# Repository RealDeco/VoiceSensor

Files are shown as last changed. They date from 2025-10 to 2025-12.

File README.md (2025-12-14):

<p align="center">
  
  
  
</p>

# 🎙️ VoiceSensor • VoiceEar • VoiceScreen

## Overview

For years, I’ve been advocating for **speakerless voice assistants** — mainly because 99% of us already have a media player in our homes, right?

This project contains three companion devices designed to work with Home Assistant and ESPHome: **VoiceSensor**, **VoiceEar**, and **VoiceScreen**.

---

## 🟦 VoiceSensor

The original prototype of this project (and the name of this repo).

It was a single device containing:

* a microphone
* a presence sensor
* a light sensor

The idea: these sensors naturally belong together and are usually mounted in the same place — high on a wall or ceiling.

---

## 🟩 VoiceEar ( the $4 VA :)

A simpler version of VoiceSensor.
It contains **only a microphone**, acting purely as an “ear” for your voice assistant.

Audio responses can be sent to **any Home Assistant media player**, so the device itself does not need a speaker.

---

## 📡 Event Outputs

All devices — VoiceSensor, VoiceEar, Respeaker Lite, and the entire Xiaozhi-ESPHome lineup — send the following events:

* **Audio Path**
  Used to route the assistant’s audio output to any chosen media player via automation.

* **Request Text**
  The recognized speech (what the user asked).
  Can be forwarded to VoiceScreen or a dashboard.

* **Response Text**
  The assistant’s reply in text form.
  Also sendable to VoiceScreen or dashboards.

* **Phase ID**
  The current pipeline step.
  Useful for showing different visuals on VoiceScreen depending on the assistant’s state.

---

## 🖥️ VoiceScreen

VoiceScreen is an ESP32-S3 display that acts as a **visual companion** to VoiceSensor, VoiceEar, and all devices from the Xiaozhi-ESPHome repository.

It waits for incoming events and updates the display accordingly.
Touching the screen sends button events back to the selected voice assistant device (e.g., Start / Stop listening).

---

<p align="center">

## 🟦 VoiceSensor DIY images
  
  
  
</p>

<p align="center">
  
  
</p>

## 🟩 VoiceEar DIY images

<p align="center">
  
  
  
  

Schematics

  
  
</p>

---

## 📄 Files

### **`VoiceSensor.yaml` (ESP32-S3 Zero + inmp441 mic + ld2410c presence sensor + bm1750 light sensor)**

* Works **only** with **ESP32-S3 Zero** (not SuperMini).
* Zero includes **2MB PSRAM**, required for on-device MicroWakeWord.
* Supports **up to 2 wake words**, processed locally.
* For outputting responses to an external media player, look in automations

---

### **`VoiceEar.yaml` (ESP32-S3 Zero + inmp441 mic, no sensors)**

* Just the "Ear" (no sensors) version of "VoiceSensor"

---

### **`respeaker-satellite-base.yaml` custom version of the  official Respeaker-Lite-ESPHome-integration**

* Use the original placement of the file (esphome/common/)

---

### **`VoiceScreen.yaml` (Guition 4" 4848S040 with no mic.)**

* Simple yaml that reads the phase id's from HA and display images accordingly
* Can also control the "virtual touch" of the voicesensor by touching the display.

---

## 🛠️ Parts List

### **VoiceSensor Setup (Full Device)**

* **ESP32-S3 Zero**
* **INMP441 microphone**
* **LD2410C presence sensor**
* **BH1750 ambient light sensor**
* **16mm push button** (GPIO 10)

### **Ear-Only Setup (No Sensors)**

* **ESP32-S3 Zero**
* **INMP441 microphone**

---

## 📦 Assembly Notes (VoiceSensor)

* Designed to fit inside a custom enclosure with accessible test pins.
* **Minimal soldering required**, unless:

  * You need custom power splitters.
  * Pin headers arrive loose or unsoldered.

---

## ✨ Features (Voicesensor)

* 🗣️ **Local Voice Assistant**
  On-device processing with LED phase feedback.

* 👤 **Presence Detection**
  LD2410C millimeter-wave radar sensor.

* 💡 **Light Level Monitoring**
  BH1750 digital luminance sensor.

* 🔘 **Push Button Input**
  For triggering actions manually.

* 🔧 **Maker-Friendly**
  Fully testable on a breadboard before final assembly.

---

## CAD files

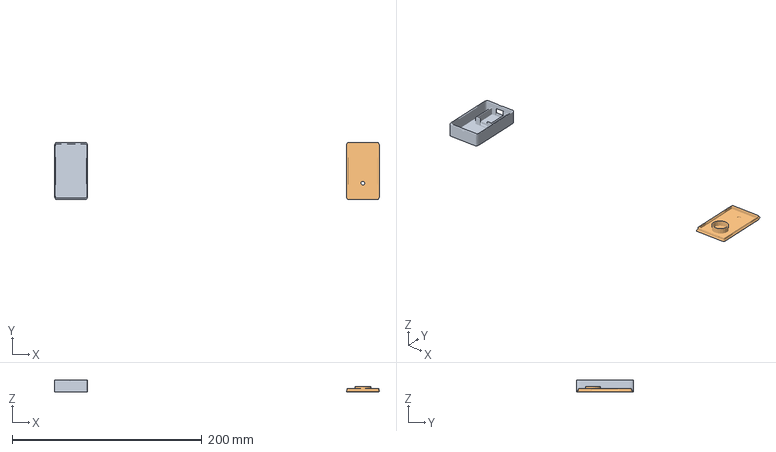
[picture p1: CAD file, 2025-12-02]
3D_files/VoiceEar.3mf
342.2 x 60.0 x 13.0 mm
ear_bottom
ear_top

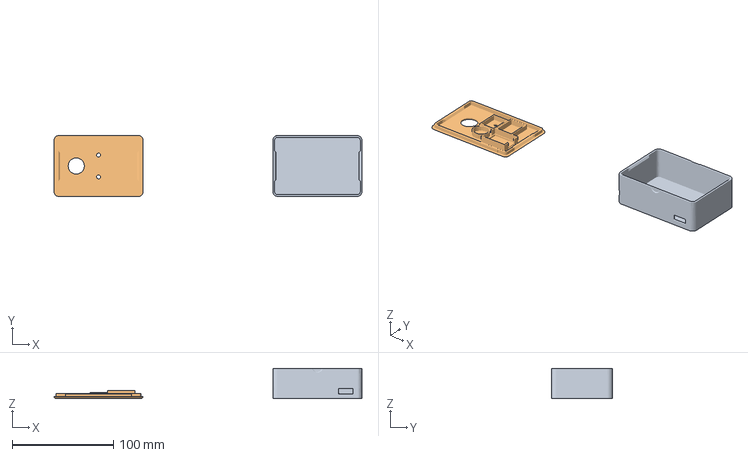
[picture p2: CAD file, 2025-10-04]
3D_files/multisensorcase.3mf
304.0 x 60.0 x 30.0 mm
multisensor_bottom.stl
multisensortop.stl

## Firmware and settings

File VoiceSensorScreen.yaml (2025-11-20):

substitutions:
  name: esphome-web-c89274
  friendly_name: Voicesensor Screen

  imagemodel1: "Luffy"
  imagewidth: "480"
  imageheight: "480"

  voiceear: "esphome_web_530014" #(voicear)
#  voiceear: "esphome_web_fa1d58" #respeaker lite

  # Voice assistant phases (must match the sending device)
  voice_assist_idle_phase_id: "1"
  voice_assist_waiting_for_command_phase_id: "2"
  voice_assist_listening_phase_id: "3"
  voice_assist_thinking_phase_id: "4"
  voice_assist_replying_phase_id: "5"
  voice_assist_not_ready_phase_id: "10"
  voice_assist_error_phase_id: "11"
  voice_assist_muted_phase_id: "12"
  voice_assist_playing_phase_id: "13"
  voice_assist_timer_finished_phase_id: "20"

  idle_illustration_file1: https://github.com/RealDeco/xiaozhi-esphome/raw/main/images/Other/${imagewidth}x${imageheight}/tron.png
  waiting_illustration_file1: https://github.com/RealDeco/xiaozhi-esphome/raw/main/images/${imagemodel1}/${imagewidth}x${imageheight}/idle.png
  listening_illustration_file1: https://github.com/RealDeco/xiaozhi-esphome/raw/main/images/${imagemodel1}/${imagewidth}x${imageheight}/listening.png
  thinking_illustration_file1: https://github.com/RealDeco/xiaozhi-esphome/raw/main/images/${imagemodel1}/${imagewidth}x${imageheight}/thinking.png
  replying_illustration_file1: https://github.com/RealDeco/xiaozhi-esphome/raw/main/images/${imagemodel1}/${imagewidth}x${imageheight}/replying.png
  loading_illustration_file1: https://github.com/RealDeco/xiaozhi-esphome/raw/main/images/${imagemodel1}/${imagewidth}x${imageheight}/loading.png
  error_illustration_file1: https://github.com/RealDeco/xiaozhi-esphome/raw/main/images/${imagemodel1}/${imagewidth}x${imageheight}/error.png
  timer_finished_illustration_file1: https://github.com/RealDeco/xiaozhi-esphome/raw/main/images/${imagemodel1}/${imagewidth}x${imageheight}/timer_finished.png
  mute_illustration_file1: https://github.com/RealDeco/xiaozhi-esphome/raw/main/images/${imagemodel1}/${imagewidth}x${imageheight}/mute.png
  playing_illustration_file1: https://github.com/RealDeco/xiaozhi-esphome/raw/main/images/${imagemodel1}/${imagewidth}x${imageheight}/playing.png

esphome:
  name: ${name}
  friendly_name: ${friendly_name}
  min_version: 2025.9.0
  name_add_mac_suffix: false
  on_boot:
    priority: 800
    then:
      - lvgl.widget.hide:
          id: request_box
      - lvgl.widget.hide:
          id: request_box_short
      - lvgl.widget.hide:
          id: response_box
      - lvgl.widget.hide:
          id: response_box_short

esp32:
  board: esp32-s3-devkitc-1
  flash_size: 16MB
  cpu_frequency: 240MHz
  framework:
    type: esp-idf
    sdkconfig_options:
      CONFIG_ESP32S3_DEFAULT_CPU_FREQ_240: "y"
      CONFIG_ESP32S3_DATA_CACHE_64KB: "y"
      CONFIG_ESP32S3_DATA_CACHE_LINE_64B: "y"

psram:
  mode: octal
  speed: 80MHz

logger:

api:
  actions:
    - action: receive_stt_text
      variables:
        stt_text: string
      then:
        - if:
            condition:
              lambda: 'return stt_text.size() < 120;'
            then:
              - lvgl.widget.show:
                  id: request_box_short
              - lvgl.widget.hide:
                  id: request_box
              - lvgl.textarea.update:
                  id: request_box_short
                  text: !lambda 'return stt_text;'
            else:
              - lvgl.widget.show:
                  id: request_box
              - lvgl.widget.hide:
                  id: request_box_short
              - lvgl.textarea.update:
                  id: request_box
                  text: !lambda 'return stt_text;'

    - action: receive_tts_text
      variables:
        tts_text: string
      then:
        - if:
            condition:
              lambda: 'return tts_text.size() < 120;'
            then:
              - lvgl.widget.show:
                  id: response_box_short
              - lvgl.widget.hide:
                  id: response_box
              - lvgl.textarea.update:
                  id: response_box_short
                  text: !lambda 'return tts_text;'
            else:
              - lvgl.widget.show:
                  id: response_box
              - lvgl.widget.hide:
                  id: response_box_short
              - lvgl.textarea.update:
                  id: response_box
                  text: !lambda 'return tts_text;'

    - action: receive_phase
      variables:
        phase: int
      then:
        - logger.log:
            format: "Voice assistant phase via API: %d"
            args: [ 'phase' ]
        - script.execute:
            id: handle_phase
            phase: !lambda 'return phase;'

ota:
  - platform: esphome

wifi:
  ssid: !secret wifi_ssid
  password: !secret wifi_password
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

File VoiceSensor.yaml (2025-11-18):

substitutions:
  name: esphome-web-530014
  friendly_name: VoiceSensor

  voice_assist_idle_phase_id: "1"
  voice_assist_waiting_for_command_phase_id: "2"
  voice_assist_listening_phase_id: "3"
  voice_assist_thinking_phase_id: "4"
  voice_assist_replying_phase_id: "5"
  voice_assist_not_ready_phase_id: "10"
  voice_assist_error_phase_id: "11"
  voice_assist_muted_phase_id: "12"
  voice_assist_playing_phase_id: "13"
  voice_assist_timer_finished_phase_id: "20"

esphome:
  name: ${name}
  friendly_name: ${friendly_name}
  min_version: 2025.9.0
  name_add_mac_suffix: false
  on_boot:
    priority: 600
    then:
      - if:
          condition:
            lambda: return id(init_in_progress);
          then:
            - lambda: id(init_in_progress) = false;
      - script.execute:
          id: set_phase
          phase: ${voice_assist_not_ready_phase_id}

esp32:
  board: esp32-s3-devkitc-1
  framework:
    type: esp-idf

psram:
  mode: quad
  speed: 80MHz

logger:

api:

ota:
- platform: esphome

wifi:
  ssid: !secret wifi_ssid
  password: !secret wifi_password

captive_portal:

i2c:
  sda: GPIO7
  scl: GPIO8
  scan: true
  id: bus_a

uart:
  id: uart_modbus
  tx_pin: 1
  rx_pin: 2
  baud_rate: 256000
  parity: NONE
  stop_bits: 1

ld2410:

sensor:
  - platform: bh1750
    name: "BH1750 Illuminance"
    address: 0x23
    update_interval: 1s

  - platform: ld2410
    light:
      name: light
    moving_distance:
      name : Moving Distance
    still_distance:
      name: Still Distance
    moving_energy:
      name: Move Energy
    still_energy:
      name: Still Energy
    detection_distance:
      name: Detection Distance
    g0:
      move_energy:
        name: g0 move energy
      still_energy:
        name: g0 still energy
    g1:
      move_energy:
        name: g1 move energy
      still_energy:
        name: g1 still energy
    g2:
      move_energy:
        name: g2 move energy
      still_energy:
        name: g2 still energy
    g3:
      move_energy:
        name: g3 move energy
      still_energy:
        name: g3 still energy
    g4:
      move_energy:
        name: g4 move energy
      still_energy:
        name: g4 still energy
    g5:
      move_energy:
        name: g5 move energy
      still_energy:
        name: g5 still energy
    g6:
      move_energy:
        name: g6 move energy
      still_energy:
        name: g6 still energy
    g7:
      move_energy:
        name: g7 move energy
      still_energy:
        name: g7 still energy
    g8:
      move_energy:
        name: g8 move energy
      still_energy:
        name: g8 still energy

number:
  - platform: ld2410
    timeout:
      name: timeout
    light_threshold:
      name: light threshold
    max_move_distance_gate:
      name: max move distance gate
    max_still_distance_gate:
      name: max still distance gate
    g0:
      move_threshold:
        name: g0 move threshold
      still_threshold:
        name: g0 still threshold
    g1:
      move_threshold:
        name: g1 move threshold
      still_threshold:
        name: g1 still threshold
    g2:
      move_threshold:
        name: g2 move threshold
      still_threshold:
        name: g2 still threshold
    g3:
      move_threshold:
        name: g3 move threshold
      still_threshold:
        name: g3 still threshold
    g4:
      move_threshold:
        name: g4 move threshold
      still_threshold:
        name: g4 still threshold
    g5:
      move_threshold:
        name: g5 move threshold
      still_threshold:
        name: g5 still threshold
    g6:
      move_threshold:
        name: g6 move threshold
      still_threshold:
        name: g6 still threshold
    g7:
      move_threshold:
        name: g7 move threshold
      still_threshold:
        name: g7 still threshold
    g8:
      move_threshold:
        name: g8 move threshold
      still_threshold:
        name: g8 still threshold

button:
  - platform: factory_reset
    id: factory_reset_btn
    internal: true

  - platform: template
    name: "Virtual Touch"
    id: virtual_touch
    on_press:
      - script.execute: handle_screen_tap
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

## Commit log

2025-11-18 Create VoiceEar.yaml
    Ear with no sensors
2025-11-20 Create Button-Card card configuration.yaml
2025-12-02 VoiceEar Enclosure for ESP32-S3 Zero + INMP441
    Remove the plastic from the INMP441 mic and cut them in half, then solder cords to that. Full pin size would be too long and removing the pins could risk damaging the mic. Both the ESP and the Mic should be a press fit, no glue needed.
    [VoiceEar.3mf]
2026-11-10 Refactor VoiceEar.yaml configuration settings
    Updated configuration for VoiceEar, including changes to speaker tracking, wake word handling, and timer management. Added new media player and silence URLs, and modified existing parameters for impr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
